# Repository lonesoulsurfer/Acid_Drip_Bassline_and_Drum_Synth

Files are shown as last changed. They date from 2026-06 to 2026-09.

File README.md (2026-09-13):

# Acid Drip - Bassline Synth, Drift Synth & Drum Machine

Youtube Video (click the image) - Acid Drip Demo (https://youtu.be/anotb2mvv04) 

An RP2040-based acid bassline synthesizer and drum machine built on the Mozzi audio library. Three instruments in one device: a 16-step acid sequencer, a second synth voice called DRIFT, and a 16-pattern drum groove box, all running simultaneously on dual cores with a 320x240 ILI9341 TFT display and 16 Cherry MX pads.

NOTE: the images of the synth are V1. V2 is what I have provided in this repo and looks a little different (extra pot for mix added).

NOTE: V5 firmware adds a second synth voice called DRIFT, pattern chaining for the acid save slots, a MIX EDIT mode for balancing all three engines against each other, and a user editable custom drum pattern, on top of everything V4 had. See DRIFT Synth, Pattern Chaining, MIX EDIT and Custom Pattern below for each.

<p align="center">
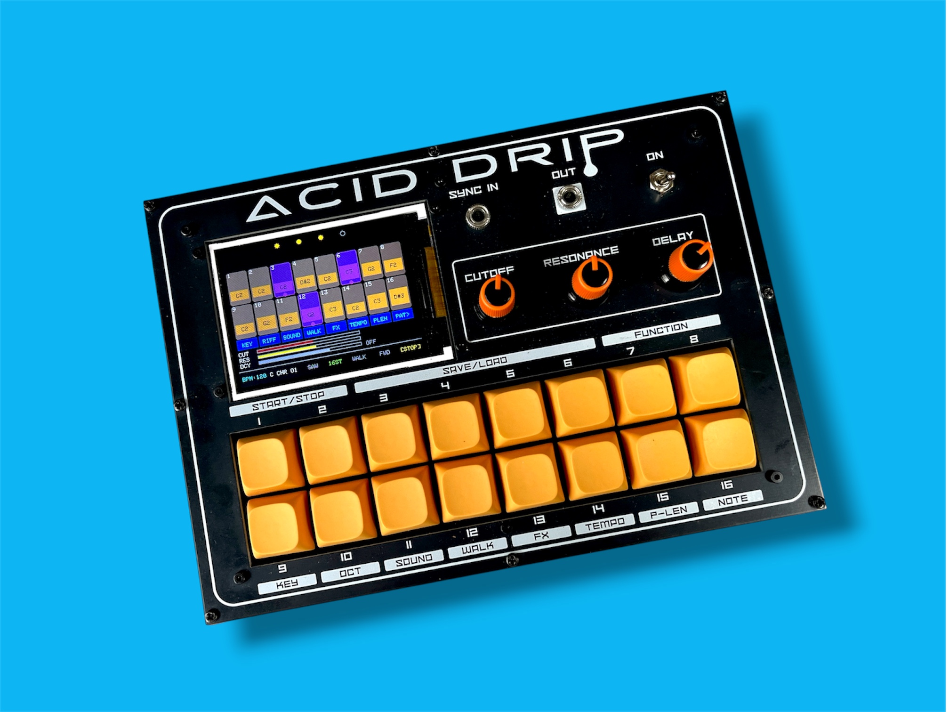
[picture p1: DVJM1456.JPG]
Acid Drip - angle view on cyan
  
  &nbsp;
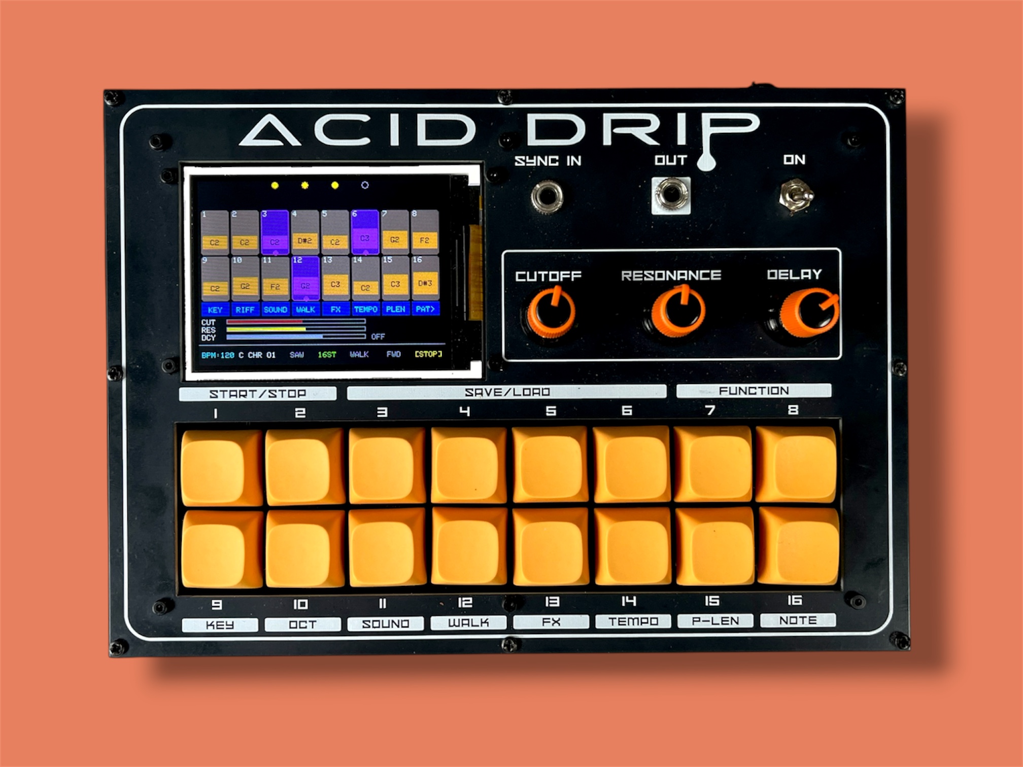
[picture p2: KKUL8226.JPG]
Acid Drip - front view on orange
  
  &nbsp;
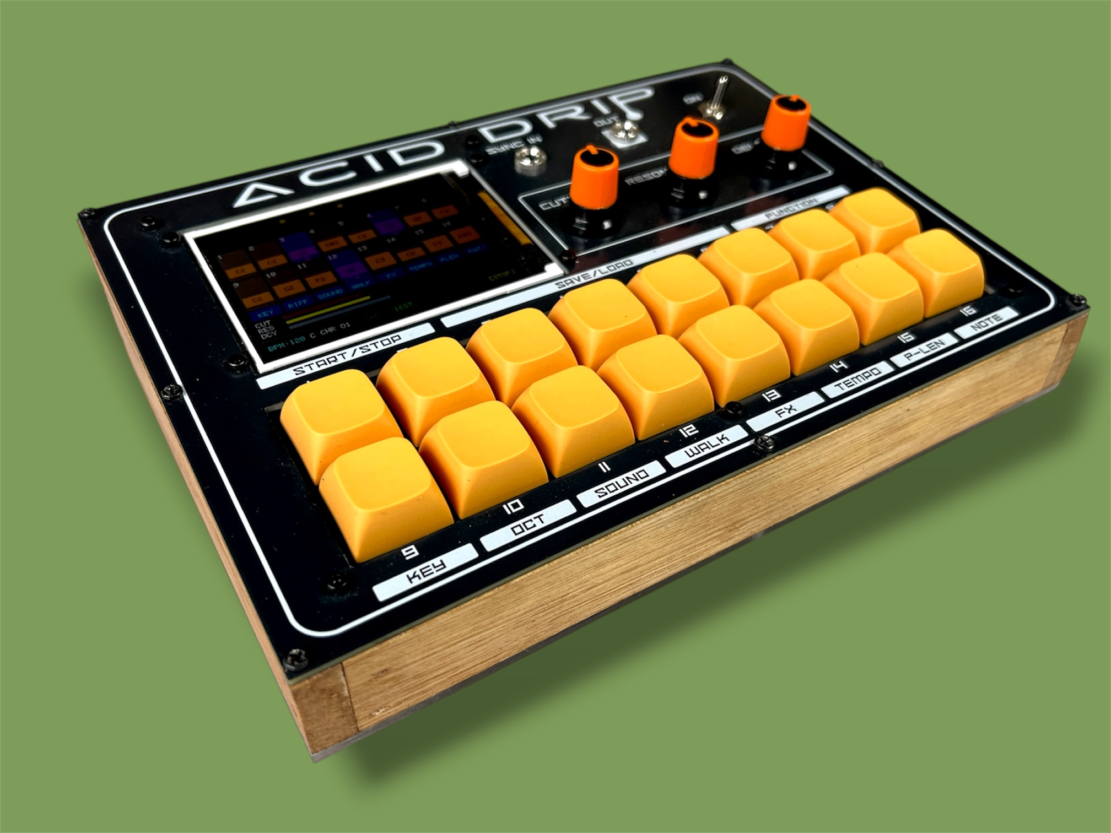
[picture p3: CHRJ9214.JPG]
Acid Drip - perspective view on green
  
</p>

---

## Hardware

| Component | Detail |
|---|---|
| MCU | RP2040 (Raspberry Pi Pico or equivalent) |
| Display | ILI9341 320x240 TFT |
| Pads | 16x Cherry MX switches (2 rows of 8) |
| Pots | 3x analog (CUT, RES, DECAY) |
| Audio out (acid) | GP15 -> 100R + 10nF RC filter -> 3.5mm jack |
| Audio out (drums) | GP2 -> 470R resistor -> 3.5mm jack. In V5 this output also carries the DRIFT synth voice, summed with the drums |
| Sync in/out | GP2 (hardware SPDT switch selects drum/DRIFT audio OR sync). Direction (in or out) is chosen from an on-screen menu at boot, see Sync In/Out below |

### Wiring

```
TFT   : SCK=GP6  SDA=GP7  RST=GP8  DC=GP10  CS=GP13
Pots  : CUT=GP26  RES=GP28  DCY=GP27
Sync  : IN/OUT=GP2
Audio : Acid=GP15   Drums/DRIFT=GP2

Top row pads (steps 1-8):
  GP14=pad1  GP12=pad2  GP11=pad3  GP16=pad4
  GP17=pad5  GP19=pad6  GP20=pad7  GP21=pad8

Bottom row pads (steps 9-16 / FUNC select):
  GP0=pad9   GP1=pad10  GP3=pad11  GP4=pad12
  GP5=pad13  GP9=pad14  GP18=pad15 GP22=pad16
```

---

## Dependencies

Install via Arduino Library Manager:

- **Mozzi** (audio synthesis engine)
- **Adafruit GFX**
- **Adafruit ILI9341**

Board package: **Raspberry Pi Pico/RP2040** (Earle Philhower core)

---

## Files

This repo has two firmware versions, each in its own folder. They are separate sketches, not meant to be merged.

### V4 (`Acid_Drip_Drum_Acid_V4`)

| File | Description |
|---|---|
| `Acid_Drip_V4.ino` | Main sketch, acid synth engine, sequencer, UI |
| `BeatMachine_V4.ino` | Drum machine tab, DrumKid engine, 8 instruments |
| `beats.h` | 16 preset drum patterns (techno, house, hip-hop, etc.) |
| `sample0-7.h` | Drum samples stored as int8 arrays in flash (PROGMEM) |

### V5 (`Acid_Drip_Drum_Acid_Drift_V5`)

| File | Description |
|---|---|
| `Acid_Drip_V5_Drum_Acid_Drift.ino` | Main sketch, acid synth engine, sequencer, UI, MIX EDIT |
| `Drift.ino` | DRIFT tab, the second synth voice engine |
| `BeatMachine2.ino` | Drum machine tab, DrumKid engine, 8 instruments, custom pattern editor |
| `beats.h` | 16 drum patterns: 15 fixed presets plus one user editable CUSTOM slot |
| `sample0-7.h` | Drum samples stored as int8 arrays in flash (PROGMEM) |

V5 adds a second synth voice (DRIFT), pattern chaining, per engine level mixing (MIX EDIT), and a user editable custom drum pattern, all on top of everything V4 already had. Pick whichever folder matches the firmware you want to flash.

---

## Acid Synthesizer

### Pad Layout

```
+---------+---------+---------+---------+---------+---------+---------+---------+
|    1    |    2    |    3    |    4    |    5    |    6    |    7    |    8    |
|  step   |  step   |  step   |  step   |  step   |  step   |  step   |  step   |
|    1    |    2    |    3    |    4    |    5    |    6    |    7    |    8    |
+---------+---------+---------+---------+---------+---------+---------+---------+
|    9    |   10    |   11    |   12    |   13    |   14    |   15    |   16    |
|   KEY   |  RIFF   |  SOUND  |  WALK   |   FX    |  TEMPO  |  PLEN   |  PAT>   |
+---------+---------+---------+---------+---------+---------+---------+---------+
  (bottom row labels show only in FUNC mode)
```

### Step Editing

| Action | Result |
|---|---|
| Short press a pad | Toggle step on/off |
| Long press x1 | Toggle accent |
| Long press x2 | Toggle glide |
| Hold pad + turn CUT pot | Set step note (scale-quantised) |

### Chords

| Chord | Action |
|---|---|
| Pads 1+2 | Play / Stop |
| Pads 1+2 (hold 0.5s) | Factory reset. V5 scopes this to whichever engine is currently the edit focus: acid or DRIFT. Drums have their own separate reset, hold pads 1+2 for 1s while in drum mode |
| Pads 7+8 | Enter / exit FUNC mode |
| Pads 9+10 | Switch to drums (from acid or DRIFT), or back to whichever of acid/DRIFT was last active (from drums) |
| Pads 9+10+11 (hold 0.5s) | V5 only. From acid: go to DRIFT. From DRIFT: back to acid. From drums: no-op, see DRIFT Synth below |
| Pads 11+12+13+14 (hold 1s) | Toggle Acid Walks easter egg |
| Pads 12+13 | Enter / exit chain-build mode |
| Pads 15+16 (hold 1s) | V5 only. Toggle MIX EDIT mode (replaces V4's Accent Edit, see below) |

### Save / Load (hold pads 7+8)

- **Tap** pads 3/4/5/6 to load from slot 1/2/3/4
- **Hold** pads 3/4/5/6 for 1 second to save to slot 1/2/3/4
- Slot status shown top-right (yellow dot = saved, grey = empty)

In V5, each slot saves and loads the acid pattern, DRIFT, and the drum beat together, whichever of the three actually have data saved in that slot. The gesture is identical from the acid screen or the drum screen; either one saves and loads all three engines at once. Loading a slot also restores each engine's play/stop state exactly as it was at save time: an engine that was stopped when you saved goes silent on load even if it is currently playing, and an engine that was playing starts up again, in sync with the others. Any engine with no data in that slot is left exactly as it currently is. Tapping an empty slot shows an "empty" indicator instead of loading anything. In V4, a slot only covered whichever single engine you were on when you saved, and play state was not part of it.

Holding pads 3+4+5+6 together for 1 second, while on the acid or DRIFT screen, wipes the acid pattern out of all 4 slots at once (a "clear all" separate from the per-slot save/hold gesture above). Because V5 slots hold all three engines together, this only clears the acid portion of each slot; any DRIFT or drum data saved in those same slot numbers is left alone. This gesture is unchanged from V4, it was already in the firmware but missing from this document.

### Pattern Chaining (V5 only)

Link the 4 save slots into a longer playback sequence, up to 16 positions, in any order, with repeats.

**Building a chain:**

1. Tap pads 12+13 together to enter chain-build mode. The screen switches to a dedicated chain-builder view.
2. Tap pads 3/4/5/6 to append that slot to the chain. Tapping the same pad more than once repeats that slot, for example tapping 3, 3, 4, 5, 6, 6 builds a chain that plays slot 1 twice, then slot 2, slot 3, and slot 4 twice.
3. Tap pads 12+13 again to exit and start playback. The chain begins automatically, even if nothing was playing yet.

Each chain position plays through one full loop of that slot's own saved pattern length before advancing to the next position: a slot saved at 16 steps plays 16 steps, a slot saved at 8 steps plays 8, and so on. When the chain reaches the end it loops back to the first position.

Pads 7+8 (FUNC) cancel an in-progress build without starting playback. Tapping 12+13 again at any other time, including while a chain is already playing, drops the current chain and starts a fresh build.

A small "CH" indicator appears next to the slot status dots whenever a chain is actively playing.

Chains are session-only and are not saved to EEPROM, so rebuilding one takes a few seconds if needed again after a power cycle. Chaining currently works in the acid synth only, not drum mode.

### FUNC Mode (enter with pads 7+8)

| Pad | Function | Options |
|-----|---|---|
| 9 | KEY | Root note: C D Eb F G Ab Bb B |
| 10 | RIFF | Load preset riff pattern: DFLT / SQNCE / FUNK / MINI / JUMP / RAVE / SYNC / DARK |
| 11 | SOUND | Synth voice: SAW / SQR / SINE / PWM / CSAW / CSQR / CSIN / SUBSQ |
| 12 | WALK | Note walk: OFF / 4TH / OCTWAVE / 5TH / BOUNCE / MIN3RD / VAMP3 / RANDOM |
| 13 | FX | Enter FX assign sub-mode |
| 14 | TEMPO | Preset BPM: 100/110/120/128/133/138/145/160, or tap repeatedly for tap tempo |
| 15 | PLEN | Pattern length: 1 / 2 / 3 / 4 / 6 / 8 / 12 / 16 |
| 16 | PAT> | Playback order: FWD / CW / ALT / REV / SKIP2 / SKIP3 / PING / RND |

> Note: there is currently no live scale-type or octave selector. `seq.scale`/`seq.octave` are only set when loading a saved patch slot.

### FX Assign (FUNC -> pad 13)

1. Press a top-row pad to select an effect:
   `None / Oct Up / Retrigger / Stutter / Maj Step / Min Step / Dom7 Step / Dim Step`
2. Press any pad 1-16 to assign that effect to that step.
3. Tap the selected FX pad again to deselect.
4. Long-hold pad 1 to clear all step effects.
5. Pads 7+8 to exit back to main screen.

### MIX EDIT (V5 only)

Hold **pads 15+16** for 1 second to enter MIX EDIT. The three pots trim the output level of each of the three engines independently:

| Pot | Engine |
|-----|---|
| CUT | Acid |
| RES | DRIFT |
| DCY | Drums |

This is a digital trim sitting on top of the physical mix pot, which only ever blends acid (GP15) against DRIFT plus drums (GP2) as one combined pair. MIX EDIT is what actually lets DRIFT be balanced against drums on its own, which the physical pot alone cannot do. Pot pickup applies here too: each pot stays inert until it has been moved past its position at the moment MIX EDIT was entered, so opening the page never snaps a level to wherever a pot happens to be sitting. Hold pads 15+16 again to exit; the three levels save to EEPROM automatically and persist across power cycles until changed again.

Accent Edit mode from V4 has been removed in V5 and replaced by MIX EDIT on the same pads 15+16 gesture. Accent tone is now a fixed setting rather than something you tune live.

### Acid Walks (Easter Egg)

Hold **pads 11+12+13+14** for 1 second to toggle a hidden mode with 8 preset patterns inspired by classic acid/house tracks, each pre-loaded with its own key, tempo, length and sound. Select a pattern with pads 1-8. FUNC mode, FX assignment and drum mode all continue to work normally while active. Hold the same 4-pad chord again to exit.

---

## DRIFT Synth (V5 only)

DRIFT is a second, independent synth voice that sits alongside the acid engine, with its own 16 step pattern, its own bank of 16 selectable synth engines, and its own FUNC page. It renders digitally and sums with the drum machine on the GP2 output, so DRIFT is only heard through the drums/DRIFT output, not the acid output.

### Switching to DRIFT

Which screen pads 9+10 and 9+10+11 land you on depends on where you currently are, not a fixed rule, so here is the full table:

| Currently on | Pads 9+10 | Pads 9+10+11 (hold 0.5s) |
|---|---|---|
| Acid | Go to drums | Go to DRIFT |
| DRIFT | Go to drums | Back to acid |
| Drums | Back to whichever of acid/DRIFT was active before | No-op, stays in drums |

DRIFT is only reachable from the acid screen, not directly from drums. Pressing 9+10+11 while already in drums is a deliberate no-op rather than a shortcut into DRIFT, since a three-pad press is easy to land imprecisely and jumping straight into DRIFT from drums made it too easy to end up somewhere unintended. To get from drums to DRIFT, go back to acid first (9+10), then 9+10+11.

Switching edit focus only changes which engine the pads and pots are currently controlling, not what is audible. Acid, DRIFT and drums can all be playing at once; each is started independently and the overall balance is set by the physical mix pot and MIX EDIT (see above).

### Step Editing

Once DRIFT is the edit focus, the same 16 pad grid used for acid steps toggles DRIFT's own step pattern instead. Holding a key on the KBRD page (see FOLW below) transposes the running line live while held.

### FUNC Mode (DRIFT)

With DRIFT as the edit focus, pads 7+8 open DRIFT's own FUNC page, separate from the acid FUNC page:

| Pad | Function | Options |
|-----|---|---|
| 9 | SND1 | Synth engine, page 1 of 2: SUBSIN / DTSQR / FMBEL / RINGM / CLICK / FOLDR / PWM / UNISN |
| 10 | SND2 | Synth engine, page 2 of 2: SAW / SUBDIV / NOIZ / VOWEL / ARPG / GONG / CRUSH / GATE |
| 11 | FOLW | Pitch mode: F+8 / F-8 / F+5 / F+3 (follow the acid voice's last note, plus an interval) / FOLW (plain follow) / ARP+ / AR+- / WALK |
| 12 | ECHO | Delay: OFF / 8D / 1/4 / 4D / 1/2 / 8FB / 4FB / 2FB |
| 13 | VERB | Reverb size: OFF / SML / MED / BIG / HALL / MEDW / BIGW / WASH |
| 14 | PATT | 8 user savable pattern slots, S1 to S8. See PATT below |
| 15 | EVOL | EVOLVE generative mutation: OFF / OCTL / ADD1 / DEEP / STUT / HVY / WILD / MAX |
| 16 | REC | Pot motion recorder. See REC below |

Each of the 16 synth engines maps the CUT/RES/DCY pots slightly differently (roughly octave, a character/detune/amount control, and decay time), so the same three pots do different things depending which engine is selected.

### PATT (pattern slots)

8 slots (S1 to S8) hold DRIFT's own saved step patterns, separate from the acid save slots. A tap loads a slot (blank if nothing has been saved there yet); a hold saves whatever is currently on the grid as that slot. All 8 slots start blank. These are on/off step patterns only; what note actually plays at each step is decided separately by the FOLW/pitch mode.

### EVOLVE (EVOL)

A generative mutation system with 7 named intensity modes (OCTL / ADD1 / DEEP / STUT / HVY / WILD / MAX) on top of OFF. When active, EVOLVE periodically nudges the DRIFT line away from its recorded pattern and back again; the mode selected sets how far it wanders and how often.

### Pot Motion Recorder (REC)

Short-tap the REC pad (16) to start recording, tap again to stop. While recording, moving any of the three pots arms that pot's lane and captures its position on every step for one loop of the pattern. Release REC and the recorded lanes play back automatically each step, in time, while any pot you did not record stays live and playable as normal. Long-press REC to clear all recorded lanes. This lets a single loop carry pot automation, for example a filter sweep or a pitch rise that repeats every bar, without needing to hold the pot yourself.

---

## Beat Machine

Switch between acid and drum mode by pressing **pads 9+10 simultaneously**. In V5, holding pads 9+10+11 instead switches to DRIFT (see DRIFT Synth above). The sequencer state is preserved when switching between any of the three.

### Drum Instruments (8 tracks)

| Pad | Instrument |
|-----|---|
| 1 | Kick |
| 2 | Hi-hat (closed) |
| 3 | Snare |
| 4 | Rim |
| 5 | Tom |
| 6 | Bass 2 |
| 7 | Clap |
| 8 | Open hat |

### Pattern Selection

Short-tap any pad (1-16) to load that beat pattern. The current pattern name and number are shown on the display. Pads 1-5 double as drum edit pads (see below): a short tap selects the pattern, a long hold enters drum editing. In V5, pad 16 has an additional role: it also opens the CUSTOM pattern editor (see Custom Pattern below).

### Per-Drum Editing

Hold any of pads 1-5 (kick/hat/snare/rim/tom) and turn the pots:

- **CUT** -> pitch (exponential, pot centre = natural speed, each 64 units = one octave)
- **RES** -> decay length (exponential envelope from a 4ms blip to full sample tail)
- **DCY** -> volume

Pot pickup prevents value jumps when grabbing a control: each pot only responds once it has been physically moved past its position at the moment the pad was grabbed. Per-drum settings reset on pattern change and are saved with slots.

> Bass 2, Clap, and Open Hat (pads 6-8) cannot be edited via hold+pot. Pattern selection is their only pad function.

### Beat Machine FUNC Mode (pads 7+8)

| Label | Function | Detail |
|---|---|---|
| PTCH | Global pitch | Transposes all drums together; stacks on top of per-drum pitch |
| DRIV | Drive / saturation | Exponential pre-gain into a hard-knee saturator; top of the knob also adds bit crush |
| FILT | Bipolar DJ filter | Centre = bypass; below centre = lowpass sweep; above centre = highpass sweep |
| CHNC | Chance | Centre = as-is; below = thins existing hits (anchors held solid); above = adds ghost hits on empty steps |
| HMNZ | Humanize | Adds random velocity spread and per-hit micro-timing jitter; centre = robotic |
| SWNG | Swing | Delays odd 16th steps up to 60% of the step interval for a swung feel |
| ACNT | Accent depth | Centre = flat; above centre = on-beat emphasis; below centre = off-beat (pushed) emphasis |
| FILL | Procedural fill engine | See Fill Engine below |

All FUNC parameters except FILT and CHNC are saved with slots.

### Fill Engine (FUNC -> FILL)

The fill engine takes over the last few steps before a pattern boundary with a procedurally generated build, then lands on beat 1 with a kick and open hat.

**Pads 1-4** set the fill frequency:

| Pad | Label | Behaviour |
|-----|---|---|
| 1 | OFF | No fills |
| 2 | 1 BAR | Fill every 16 steps (4 steps long) |
| 3 | 2 BAR | Fill every 32 steps (6 steps long) |
| 4 | 4 BAR | Fill every 64 steps (8 steps long, half a bar) |

**Pads 5-8** set the fill type:

| Pad | Label | Behaviour |
|-----|---|---|
| 5 | HATS | Closed-hat build opening to an open hat on the tail; kick holds the floor |
| 6 | CLAP | Clap build over a steady half-time kick |
| 7 | SNARE | Flat snare rush with no kick; the landing slams |
| 8 | KIT | Descending tom for the first 70% of the window, then snare into the landing; KIT also adds a clap on the "1" |

> Pads 7 and 8 are also the FUNC-exit chord. SNARE and KIT selections register on release so the exit gesture takes priority.

**Editing the fill sound:** while in the FILL slot, the three pots control the lead voice's own pitch, decay length, and volume independently of the pattern's drum settings. These are saved with slots.

Density accelerates into the landing: the final quarter of the fill window schedules additional 32nd-note in-between hits so the build feels like it rushes into the "1".

### Preset Patterns

16 patterns selectable from the pad grid:

| # | Short name | Full name |
|---|---|---|
| 1 | BASC | BASIC |
| 2 | HOUS | HOUSE |
| 3 | TECH | TECHNO |
| 4 | ACID | ACID TRACK |
| 5 | HSOC | HI STATE |
| 6 | FUNK | FUNKY |
| 7 | SWNG | SWING |
| 8 | BKBT | BREAKBEAT |
| 9 | MINM | MINIMAL |
| 10 | LATN | LATIN |
| 11 | PCFC | PACIFIC ST |
| 12 | BLMN | BLUE MONDAY |
| 13 | DNBT | DRUM N BASS |
| 14 | VOOD | VOODOO RAY |
| 15 | GBLD | BUILD DOWN |
| 16 | CUST | CUSTOM (V5 only, user editable, see Custom Pattern below) |

> V4's pattern 16 was a fixed preset called JACK BEAT. V5 replaces it with the user editable CUSTOM slot described below.

### Custom Pattern (Pad 16, V5 only)

Pattern slot 16 is CUSTOM: a blank, user editable pattern rather than a fixed preset.

- **Quick tap pad 16** while not already editing to enter custom edit mode straight away. No hold required.
- **Tap pad 16** again once you are editing to toggle step 16 for whichever drum voice is currently selected, the same as tapping any other step pad.
- **Turn any pot** at any time while editing to set pitch/length/volume for the current voice, live, the same as normal per-drum editing.
- **Hold pad 16 for 0.4 seconds** to cycle to the next drum voice.
- **Hold pad 16 for 0.8 seconds** to exit and save.
- **Hold pad 16 for 2 seconds**, from either state, to wipe the whole custom pattern and start again.

A live legend appears along the bottom of the screen the moment pad 16 is pressed, listing each of the tiers above. They start out white and light up in their own colour as your hold time reaches that tier, so you can see what letting go will do before you commit to it.

### Save / Load (drum mode)

Same gesture as the acid synth: hold pads 7+8, then tap pads 3-6 to load from slot 1-4 or hold pads 3-6 for one second to save. This is the same unified save/load described above, it saves and loads acid, DRIFT and the drum beat together (including each engine's play/stop state) no matter which screen you trigger it from. Per-drum pitch/length/volume, global FUNC parameters, tempo, swing, fill settings, and the selected pattern are all stored as part of it.

Holding pads 3+4+5+6 together for 1 second while in drum mode (and not holding pads 7+8) wipes the drum beat out of all 4 slots at once, the drum-side equivalent of the acid clear-all gesture above. It only clears the drum portion of each slot; acid and DRIFT data saved in those same slot numbers is untouched.

---

## Sync In / Sync Out / Drum Mode (GP2)

GP2 is shared between drum audio output (in V5, also the DRIFT synth voice, which sums with the drums on the same output) and the sync clock jack, in either direction. A physical **SPDT switch on the PCB** routes the pin to either function.

**Boot detection selects the mode and, for sync, the direction:**

- **Drum mode (default):** GP2 is claimed by PWMAudio DMA and outputs drum (and, in V5, DRIFT) audio. Switch in the DRUMS position. Hold nothing at power-on.
- **Sync In mode:** Hold **pad 14** at power-on. A "SYNC MODE" menu appears; press **pad 1** for Sync In. GP2 is configured as a digital input and listens for an external clock pulse, driving this device's tempo from it. Switch in the SYNC position.
- **Sync Out mode:** Hold **pad 14** at power-on. On the same "SYNC MODE" menu, press **pad 2** for Sync Out. GP2 becomes a clock output instead, generating a DIN-sync-style pulse train (24 pulses per quarter note, matching the TB-303/808/909 standard) from this device's own tempo, so it can drive other gear as the master. Switch in the SYNC position.

A cyan "SYNC MODE" menu appears when pad 14 is held at boot, prompting for pad 1 (Sync In) or pad 2 (Sync Out); a "SYNC IN ACTIVE" or "SYNC OUT ACTIVE" confirmation follows briefly once chosen.

Sync Out only emits pulses while the acid transport is running (pads 1+2). It goes idle (line held low) when stopped rather than free-running through a stopped pattern. The pulse width is fixed at 2ms regardless of tempo. The info bar's "S" indicator (top right) is cyan for Sync In and magenta for Sync Out, so you can tell direction at a glance while playing.

> The switch position and the held pad must match. If the switch is in SYNC position but the device boots into drum mode, GP2 will try to drive audio into the sync signal line. In V5, sync mode (either direction) silences drums and DRIFT together, since both share GP2 with the sync jack; the acid voice on GP15 is unaffected either way. Sync In and Sync Out cannot run at the same time, since they both need sole use of GP2, one as an input, one as an output; the boot menu is where you pick one for that session.

---

## Architecture Notes

The firmware runs on both RP2040 cores:

- **Core 0**: Mozzi audio engine (acid synthesis, DRIFT synthesis in V5, and drum mixing), pad scanning, sequencer logic
- **Core 1**: TFT display rendering, drum sample buffer filling (via `bmFillDrumBuffer`)

The two cores communicate via the RP2040 inter-core FIFO. All SPI/TFT calls happen exclusively on core 1.

The drum clock is driven directly by the acid sequencer's `advanceStep()` call rather than an independent timer. In V5, DRIFT's own step advance is driven from the same call. This guarantees zero drift between all engines at all tempos and pattern lengths.

The drum audio path on GP2 uses a separate `PWMAudio` DMA instance at 488kHz carrier (versus Mozzi's 48kHz on GP15). This prevents carrier-frequency beating between the two audio outputs that would otherwise cause the acid synth to sound quieter when drums (and, in V5, DRIFT) are playing. DRIFT is rendered digitally and summed into this same GP2 path alongside the drums, rather than having a separate output of its own.

MIX EDIT's per-engine levels (V5) are a digital trim applied on top of this, independent of the physical mix pot, and are stored in EEPROM alongside the other saved settings.

---

## Credits

- Acid synthesis engine adapted from *Badass Bass*  https://www.youtube.com/watch?v=MvDILHYImc4
- Drum engine adapted from **DrumKid** by Matt Bradshaw  https://www.youtube.com/watch?v=509iZGjnVhM
- Built with the [Mozzi](https://sensorium.github.io/Mozzi/) audio library
- Hardware design and firmware by Marcus ([lonesoulsurfer](https://github.com/lonesoulsurfer))

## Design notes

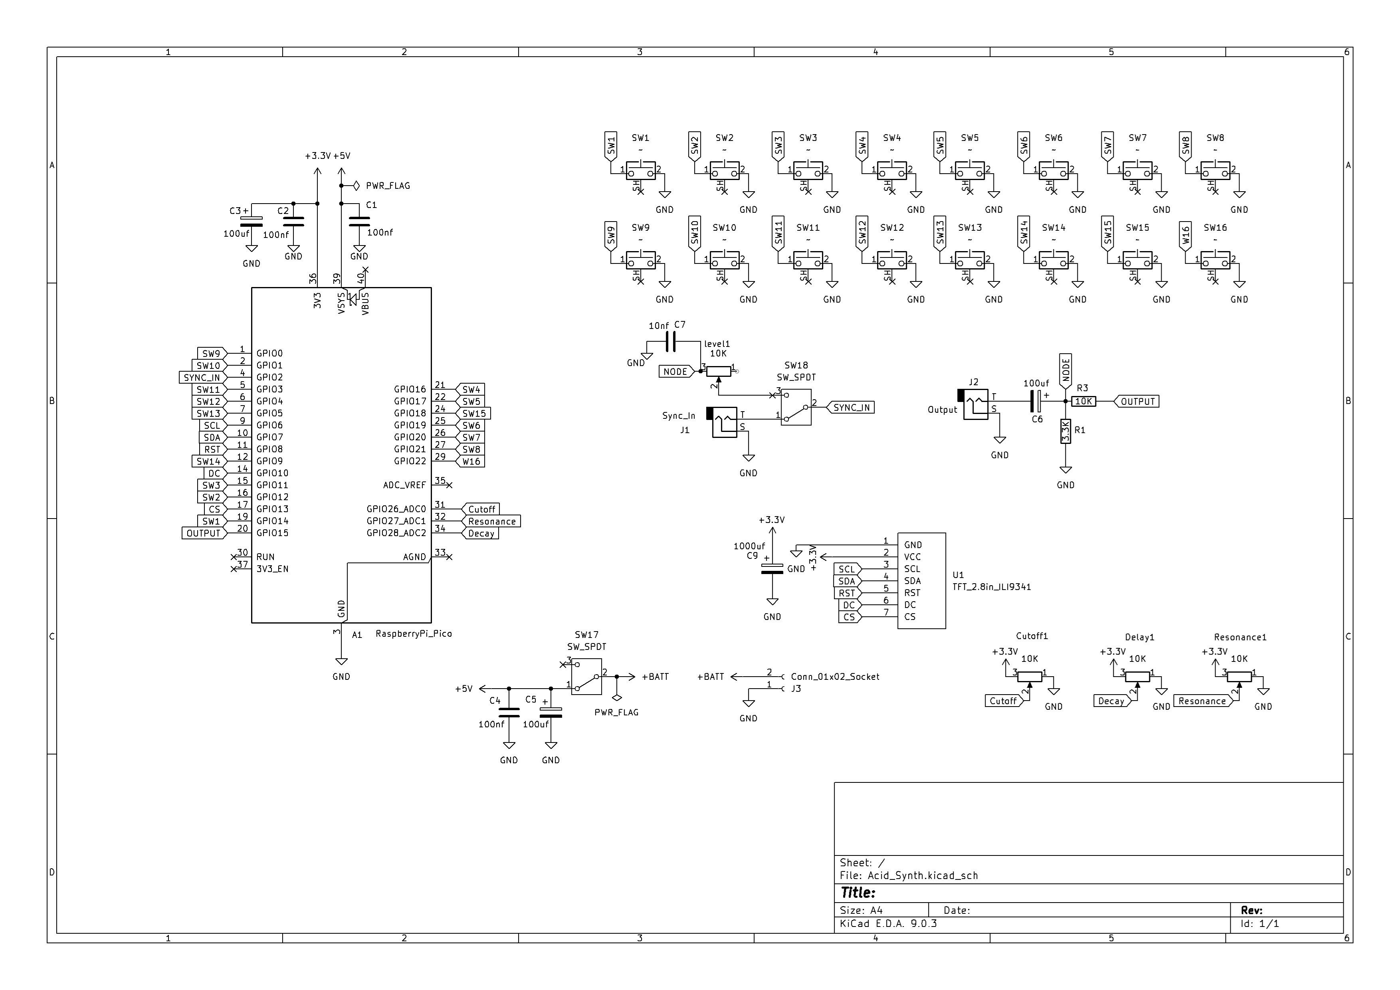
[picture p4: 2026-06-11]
Schematic.png

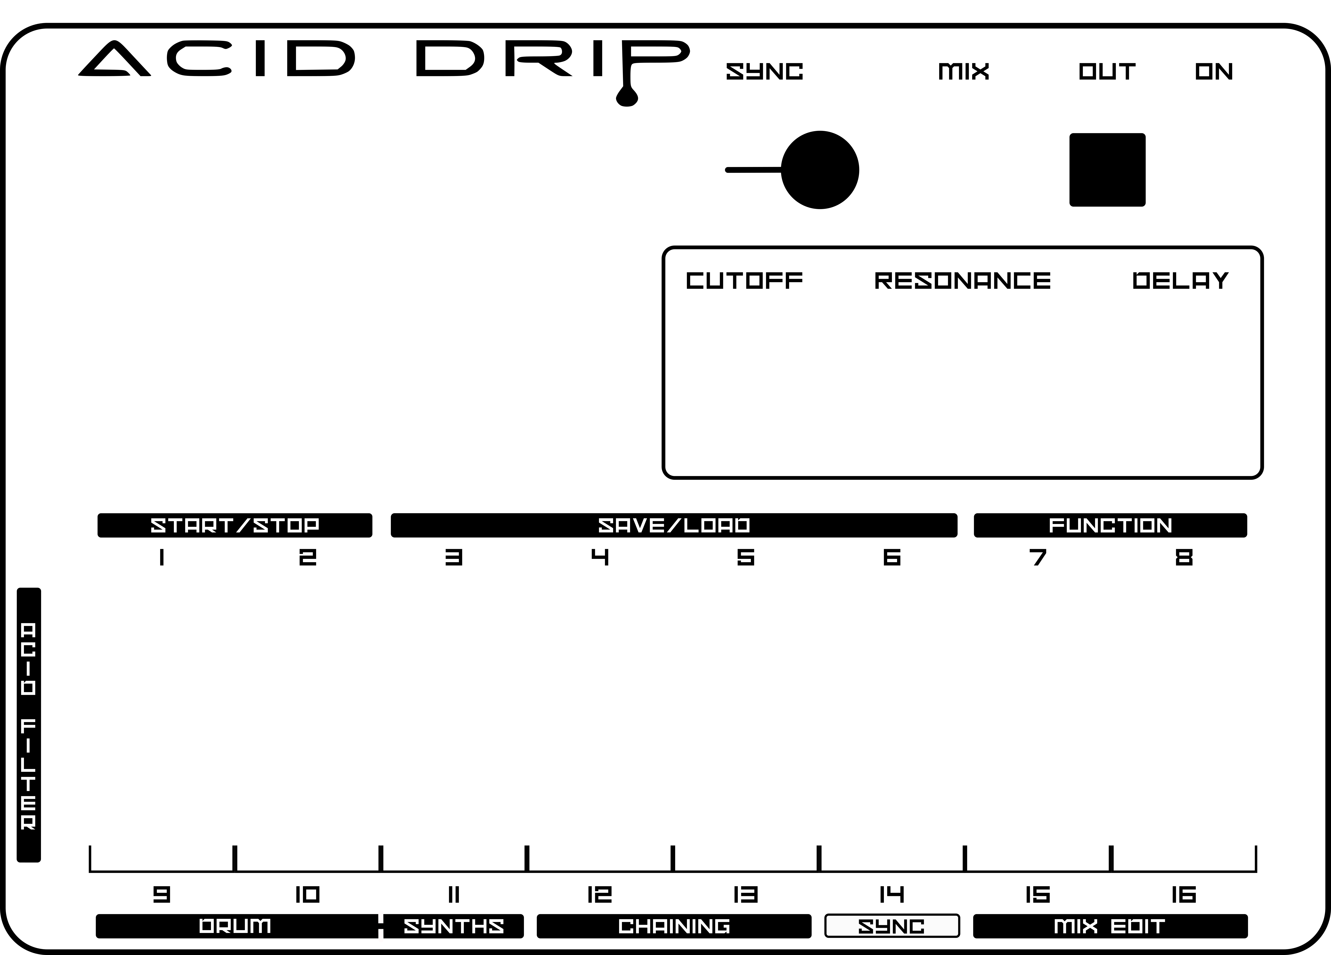
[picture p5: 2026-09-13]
Front Panel Design/Acid - Front Panel - Inkscape.png

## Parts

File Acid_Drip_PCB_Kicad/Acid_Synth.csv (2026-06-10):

Reference | Qty | Value | DNP | Exclude from BOM | Exclude from Board | Footprint | Datasheet
A1 | 1 | RaspberryPi_Pico |  |  |  | Module_RaspberryPi_Pico:RaspberryPi_Pico_Common | https://datasheets.raspberrypi.com/pico/pico-datasheet.pdf
C1,C2,C4 | 3 | 100nf |  |  |  | Capacitor_THT:C_Disc_D4.3mm_W1.9mm_P5.00mm | ~
C3,C5,C6 | 3 | 100uf |  |  |  | Capacitor_THT:CP_Radial_D5.0mm_P2.00mm | ~
C7 | 1 | 10nf |  |  |  | Capacitor_THT:C_Disc_D4.3mm_W1.9mm_P5.00mm | ~
C9 | 1 | 1000uf |  |  |  | Capacitor_THT:CP_Radial_D6.3mm_P2.50mm | ~
Cutoff1,Delay1,Resonance1 | 3 | 10K |  |  |  | Potentiometer_THT:Potentiometer_Alps_RK09K_Single_Vertical | ~
J1 | 1 | Sync_In |  |  |  | Connector_Audio:Jack_3.5mm_QingPu_WQP-PJ398SM_Vertical_CircularHoles | ~
J2 | 1 | Output |  |  |  | Connector_Audio:Jack_3.5mm_QingPu_WQP-PJ398SM_Vertical_CircularHoles | ~
J3 | 1 | Conn_01x02_Socket |  |  |  | Connector_JST:JST_PH_B2B-PH-K_1x02_P2.00mm_Vertical | ~
level1 | 1 | 50K |  |  |  | Potentiometer_THT:Potentiometer_Alps_RK09K_Single_Vertical | ~
R1 | 1 | 3.3K |  |  |  | Resistor_THT:R_Axial_DIN0207_L6.3mm_D2.5mm_P10.16mm_Horizontal | ~
R3 | 1 | 10K |  |  |  | Resistor_THT:R_Axial_DIN0207_L6.3mm_D2.5mm_P10.16mm_Horizontal | ~
SW1,SW2,SW3,SW4,SW5,SW6,SW7,SW8,SW9,SW10,SW11,SW12,SW13,SW14,SW15,SW16 | 16 | ~ |  |  |  | Button_Switch_Keyboard:SW_Cherry_MX_1.00u_PCB | ~
SW17,SW18 | 2 | SW_SPDT |  |  |  | MyProject:SW_SPDT_Toggle_QuarterInch_Bushing | ~
U1 | 1 | TFT_2.8in_ILI9341 |  |  |  | MyProject:TFT_2.8in_ILI9341

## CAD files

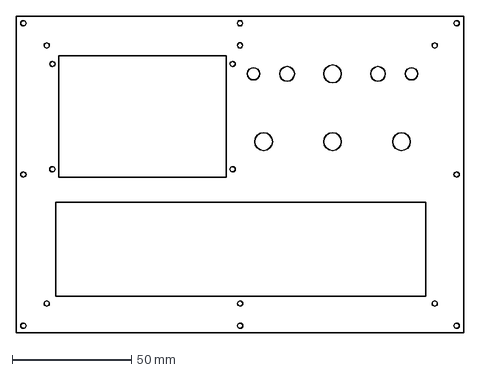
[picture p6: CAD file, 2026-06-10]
Front Panel Design/front panel - Fusion.dxf
188.0 x 133.0 mm

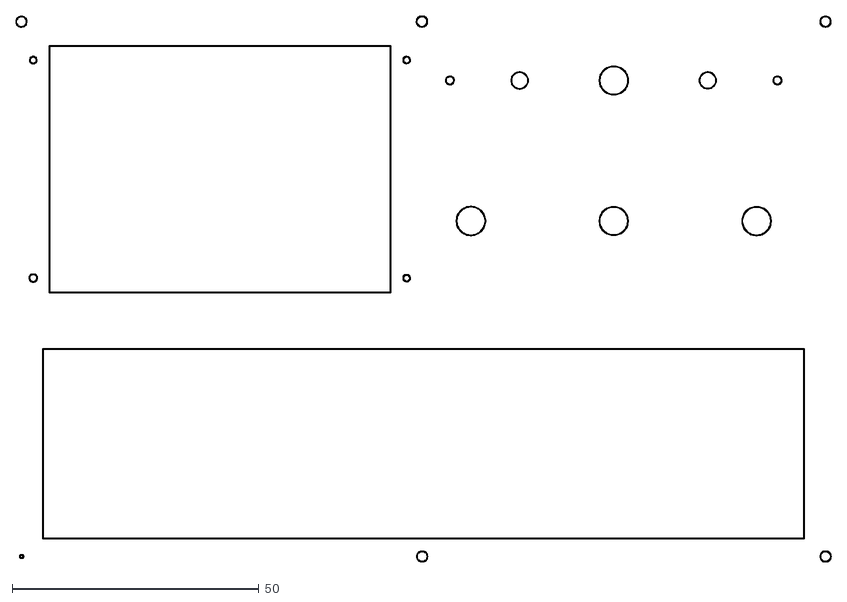
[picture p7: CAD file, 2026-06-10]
Front Panel Design/PCB/Acid_Synth-User_1.dxf
165.2 x 110.7

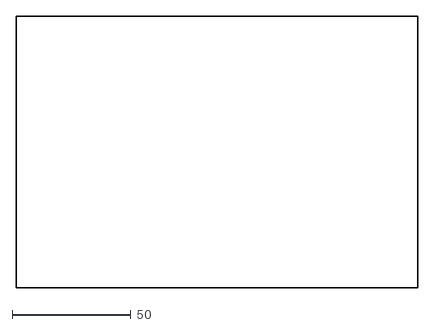
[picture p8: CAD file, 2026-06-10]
Front Panel Design/PCB/Acid_Synth-Edge_Cuts.dxf
169.0 x 114.5

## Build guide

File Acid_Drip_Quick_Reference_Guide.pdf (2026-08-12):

# Acid Drip

Bassline synth, DRIFT synth and drum machine. Quick reference guide (V5)

## Acid Pad Layout

1
Step 1

2
Step 2

3
Step 3

4
Step 4

5
Step 5

6
Step 6

7
Step 7

8
Step 8

9
KEY

10
RIFF

11
SOUND

### 12 WALK

13
FX

14
TEMPO

15
PLEN

16
PAT>

Bottom row labels only show in FUNC mode. Steps 9-16 are the same 8 pads.
Step Editing
ACTION | RESULT
Short press pad | Toggle step on/off
Long press x1 | Toggle accent
Long press x2 | Toggle glide
Hold pad + turn CUT | Set step note

## Core Chords

CHORD | ACTION
1+2 | Play / Stop
1+2 hold 0.5s | Reset current engine (acid/DRIFT). Drums: hold 1s in drum
mode
7+8 | Enter / exit FUNC mode
9+10 | Switch to drums, or back to acid/DRIFT
9+10+11 hold 0.5s | Acid to DRIFT and back. No-op from drums
11+12+13+14 hold
1s

Acid Walks easter egg

12+13 | Enter / exit chain-build mode
15+16 hold 1s | Toggle MIX EDIT mode

Save / Load (hold 7+8)

Tap 3/4/5/6 | Load slot 1/2/3/4
Hold 3/4/5/6 for 1s | Save to slot 1/2/3/4
Hold 3+4+5+6 for 1s Clear acid from all 4 slots (drum mode: clears drums instead)

Each slot saves acid, DRIFT and the drum beat together, plus play/stop state. Works from any screen.

## FUNC Mode (hold 7+8 to enter)

PAD | FUNCTION | OPTIONS
9 | KEY | Root note: C D Eb F G Ab Bb B
10 | RIFF | DFLT / SQNCE / FUNK / MINI / JUMP / RAVE / SYNC / DARK
11 | SOUND | SAW / SQR / SINE / PWM / CSAW / CSQR / CSIN / SUBSQ
12 | WALK | OFF / 4TH / OCTWAVE / 5TH / BOUNCE / MIN3RD / VAMP3 / RANDOM
13 | FX | Enter FX assign sub-mode
14 | TEMPO | Preset BPM or tap tempo
15 | PLEN | Pattern length: 1/2/3/4/6/8/12/16
16 | PAT> | FWD / CW / ALT / REV / SKIP2 / SKIP3 / PING / RND

FX Assign (FUNC, pad 13): press a top-row pad to pick an effect (None / Oct Up / Retrigger / Stutter / Maj Step / Min Step / Dom7 Step / Dim Step), then press any step pad to assign it. Tap the effect pad again to deselect. Long-hold pad 1 to clear all.

## Pattern Chaining

Link the 4 save slots into a sequence of up to 16 positions, with repeats.

1 | Tap 12+13 to enter chain-build mode
2 | Tap 3/4/5/6 to append that slot. Tap the same pad again to repeat it
3 | Tap 12+13 again to exit and start playback

Each position plays one full loop of that slot's own pattern length. Acid only, not drum mode. Chains are not saved to EEPROM.

## MIX EDIT

Hold 15+16 for 1s to trim the level of each engine independently.

POT | ENGINE
CUT | Acid
RES | DRIFT
DCY | Drums

Levels save to EEPROM automatically. Hold 15+16 again to exit.

## DRIFT Synth

A second, independent synth voice. Sums into the drums output (GP2).

## Switching Engines

CURRENTLY ON | 9+10 | 9+10+11 (HOLD 0.5S)
Acid | Go to drums | Go to DRIFT
DRIFT | Go to drums | Back to acid
Drums | Back to acid/DRIFT | No-op

DRIFT is only reachable from the acid screen. From drums, go back to acid first, then 9+10+11. Acid, DRIFT and drums can all play at once, switching only changes which one the pads/pots control.

## DRIFT FUNC Mode (7+8)

PAD | FUNCTION
9 | SND1, engine page 1 of 2
10 | SND2, engine page 2 of 2
11 | FOLW, pitch mode
12 | ECHO, delay
13 | VERB, reverb size
14 | PATT, 8 pattern slots
15 | EVOL, EVOLVE mutation
16 | REC, pot motion recorder

SND1

SUBSIN / DTSQR / FMBEL / RINGM / CLICK / FOLDR / PWM / UNISN SND2

SAW / SUBDIV / NOIZ / VOWEL / ARPG / GONG / CRUSH / GATE
FOLW (pitch mode)

F+8 / F-8 / F+5 / F+3 (follow acid's last note, plus an interval) / FOLW (plain follow) / ARP+ / AR+- / WALK EVOL (EVOLVE intensity)

OFF / OCTL / ADD1 / DEEP / STUT / HVY / WILD / MAX

## PATT, EVOLVE & REC

PATT 8 slots (S1-S8) for DRIFT's own step patterns. Tap loads, hold saves. Note/pitch is set separately by FOLW.
EVOLVE Periodically nudges the DRIFT line away from its recorded pattern and back. Intensity sets how far and how often.
REC Short-tap to start/stop recording pot movement over one loop. Recorded lanes play back automatically; unrecorded pots stay live. Long-press to clear.

## Beat Machine

Switch with pads 9+10. Sequencer state is preserved across all three engines.

## Drum Instruments

1 | Kick
2 | Hi-hat (closed)
3 | Snare
4 | Rim
5 | Tom
6 | Bass 2
7 | Clap
8 | Open hat

Short-tap any pad 1-16 to load that pattern. Pads 1-5 also double as drum edit pads (short tap = select, long hold = edit). Pads 6-8 are select-only.
Per-Drum Editing (hold pad 1-5)
CUT | Pitch
RES | Decay length
DCY | Volume

Custom Pattern (Pad 16)

Quick tap | Enter custom edit mode
Tap while editing | Toggle step 16 for current voice
Turn any pot | Set pitch/length/volume for current voice
Hold 0.5s | Cycle to next drum voice
Hold 1s | Exit and save
Hold 1.5s | Wipe pattern and restart

## Beat Machine FUNC (7+8)

LABEL | FUNCTION
PTCH | Global pitch, stacks on per-drum
DRIV | Drive / saturation, bit crush at top
FILT | Bipolar DJ filter (low/high sweep)
CHNC | Chance - thin or add ghost hits
HMNZ | Humanize - velocity & timing jitter
SWNG | Swing on odd 16th steps
ACNT | Accent depth, on/off-beat emphasis
FILL | Procedural fill engine, see below

Fill Engine

Pads 1-4 (frequency): OFF / 1 BAR / 2 BAR / 4 BAR
Pads 5-8 (type): HATS / CLAP / SNARE / KIT
Pots control the fill voice's pitch, decay and volume while FILL is selected. Density accelerates into the landing beat.

## 16 Preset Patterns

1 BASIC | 2 HOUSE | 3 TECHNO | 4 ACID TRACK
5 HI STATE | 6 FUNKY | 7 SWING | 8 BREAKBEAT
9 MINIMAL | 10 LATIN | 11 PACIFIC ST | 12 BLUE MONDAY
13 DRUM N BASS | 14 VOODOO RAY | 15 BUILD DOWN | 16 CUSTOM

Sync In / Out: hold pad 14 at power-on for a SYNC MODE menu. Press pad 1 for Sync In (external clock drives this device's tempo) or pad 2 for Sync Out (this device sends a 24 PPQN clock to other gear). Either way GP2 is taken from drum/DRIFT audio for that session, and requires the PCB switch in the SYNC position.

Acid Drip V5. Hardware and firmware by Marcus (lonesoulsurfer), github.com/lonesoulsurfer

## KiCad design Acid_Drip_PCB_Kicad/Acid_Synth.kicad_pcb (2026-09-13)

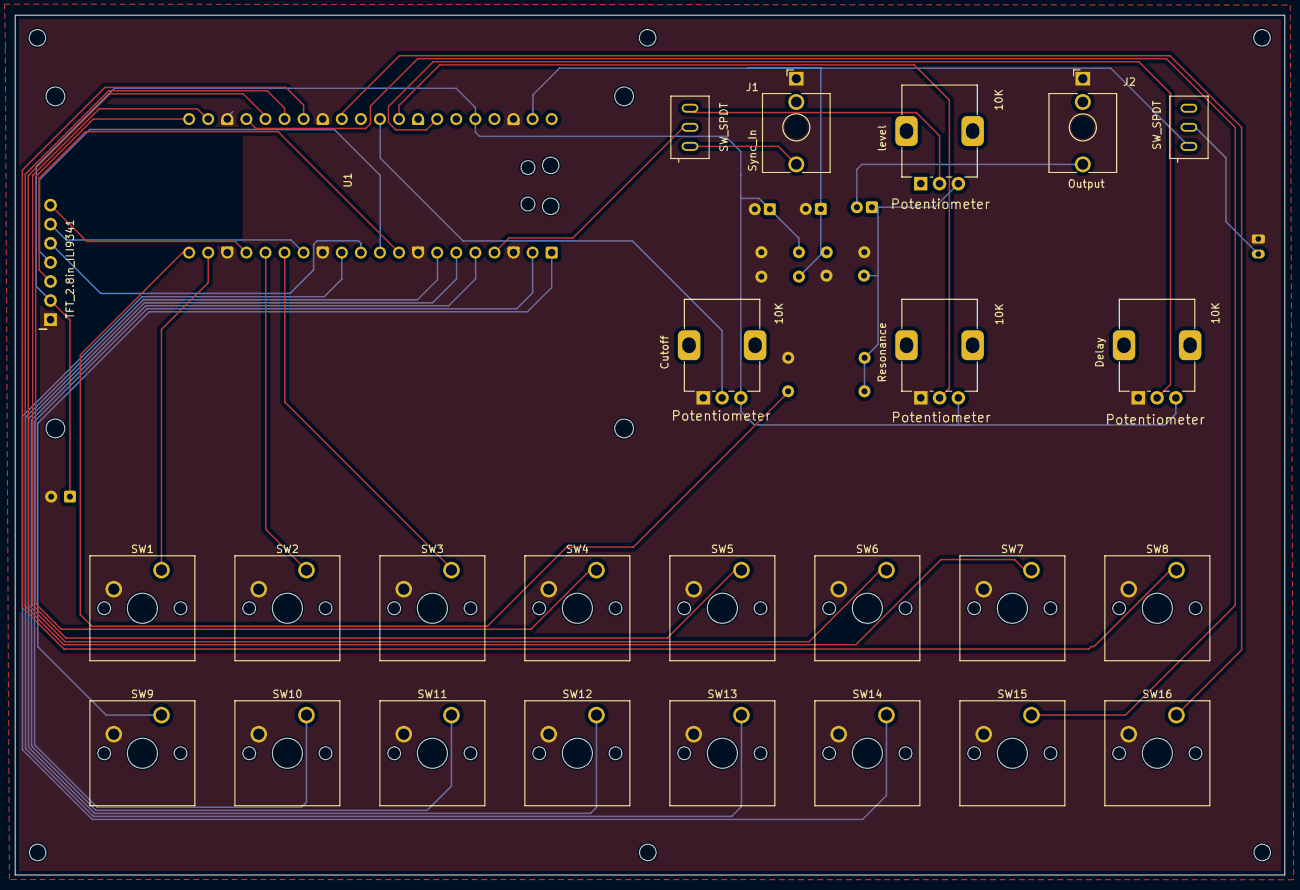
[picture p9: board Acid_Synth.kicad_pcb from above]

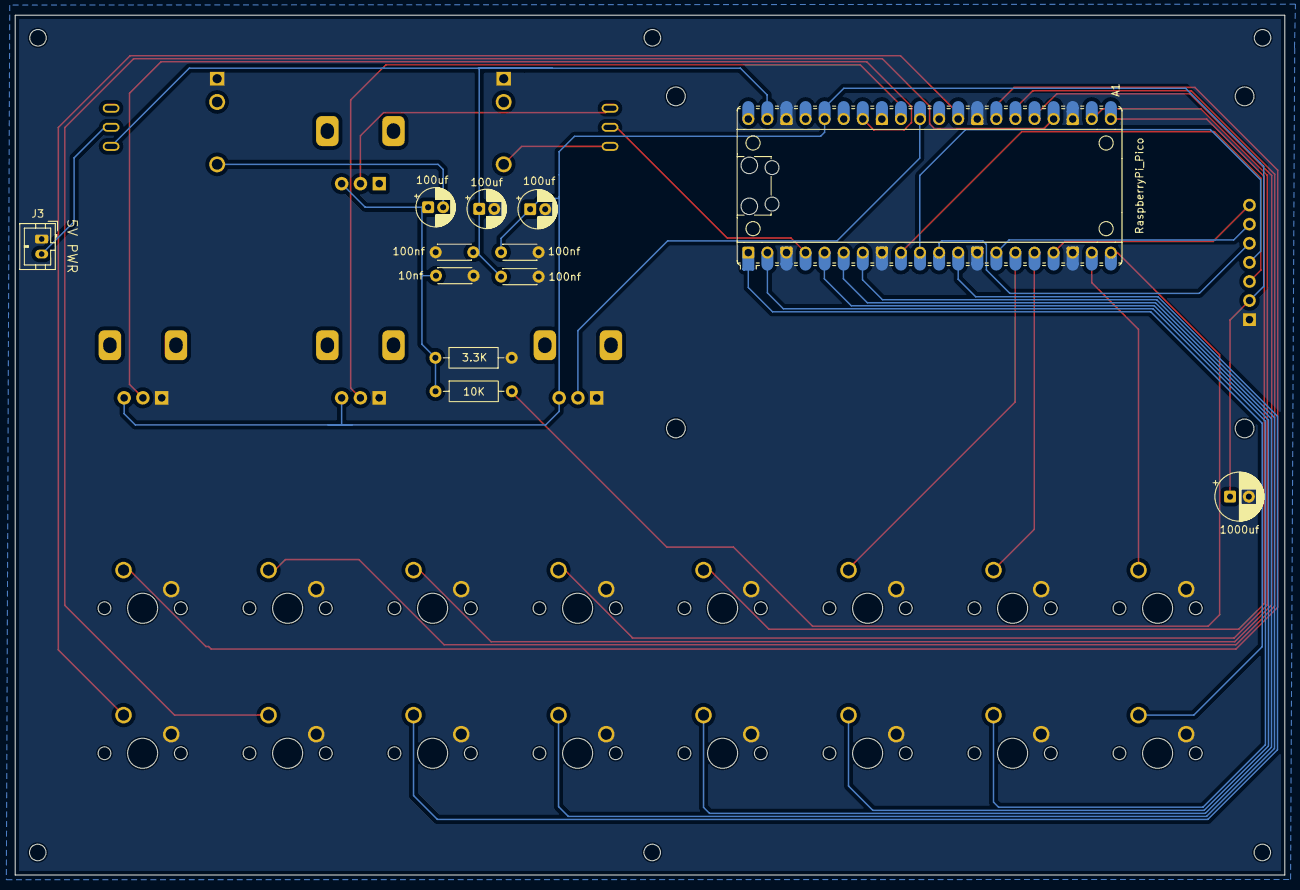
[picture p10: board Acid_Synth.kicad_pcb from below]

Board: 2 copper layers, 169.0 x 114.4 mm, 37 parts (12 on the bottom side), 33 nets.

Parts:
A1: RaspberryPi_Pico; RaspberryPi_Pico_Common
C1, C2, C4: 100nf; C_Disc_D4.3mm_W1.9mm_P5.00mm
C3, C5, C6: 100uf; CP_Radial_D5.0mm_P2.00mm
C7: 10nf; C_Disc_D4.3mm_W1.9mm_P5.00mm
C9: 1000uf; CP_Radial_D6.3mm_P2.50mm
Cutoff: 10K; Potentiometer_Alps_RK09K_Single_Vertical
Delay: 10K; Potentiometer_Alps_RK09K_Single_Vertical
J1: Sync_In; Jack_3.5mm_QingPu_WQP-PJ398SM_Vertical_CircularHoles
J2: Output; Jack_3.5mm_QingPu_WQP-PJ398SM_Vertical_CircularHoles
J3: Conn_01x02_Socket; JST_PH_B2B-PH-K_1x02_P2.00mm_Vertical
R1: 3.3K; R_Axial_DIN0207_L6.3mm_D2.5mm_P10.16mm_Horizontal
R3: 10K; R_Axial_DIN0207_L6.3mm_D2.5mm_P10.16mm_Horizontal
Resonance: 10K; Potentiometer_Alps_RK09K_Single_Vertical
SW1, SW2, SW3, SW4, SW5, SW6, SW7, SW8, SW9, SW10, SW11, SW12, SW13, SW14, SW15, SW16: SW_Cherry_MX_1.00u_PCB
SW17, SW18: SW_SPDT; SW_SPDT_Toggle_QuarterInch_Bushing
U1: TFT_2.8in_ILI9341
level: 10K; Potentiometer_Alps_RK09K_Single_Vertical

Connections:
+3.3V: A1.36 (3V3), C2.1, C3.1, C9.1, Cutoff.3, Delay.3, Resonance.3, U1.2 (VCC)
+5V: A1.39 (VSYS), C1.1, C4.1, C5.1, SW17.1 (A)
+BATT: J3.2, SW17.2 (B)
CS: A1.17 (GPIO13), U1.7 (CS)
Cutoff: A1.31 (GPIO26_ADC0), Cutoff.2
DC: A1.14 (GPIO10), U1.6 (DC)
Decay: A1.34 (GPIO28_ADC2), Delay.2
GND: A1.3 (GND), A1.8 (GND), A1.13 (GND), A1.18 (GND), A1.23 (GND), A1.28 (GND), A1.38 (GND), C1.2, C2.2, C3.2, C4.2, C5.2, C7.1, C9.2, Cutoff.1, Delay.1, J1.S, J2.S, J3.1, R1.1, Resonance.1, SW1.2, SW2.2, SW3.2, SW4.2, SW5.2, SW6.2, SW7.2, SW8.2, SW9.2, SW10.2, SW11.2, SW12.2, SW13.2, SW14.2, SW15.2, SW16.2, U1.1 (GND)
NODE: C6.1, C7.2, R1.2, R3.1, level.3
unnamed: C6.2, J2.T
unnamed: J1.T, SW18.1 (A)
OUTPUT: A1.20 (GPIO15), R3.2
RST: A1.11 (GPIO8), U1.5 (RST)
Resonance: A1.32 (GPIO27_ADC1), Resonance.2
SCL: A1.9 (GPIO6), U1.3 (SCL)
SDA: A1.10 (GPIO7), U1.4 (SDA)
SW1: A1.19 (GPIO14), SW1.1
SW2: A1.16 (GPIO12), SW2.1
SW3: A1.15 (GPIO11), SW3.1
SW4: A1.21 (GPIO16), SW4.1
SW5: A1.22 (GPIO17), SW5.1
SW6: A1.25 (GPIO19), SW6.1
SW7: A1.26 (GPIO20), SW7.1
SW8: A1.27 (GPIO21), SW8.1
SW9: A1.1 (GPIO0), SW9.1
SW10: A1.2 (GPIO1), SW10.1
SW11: A1.5 (GPIO3), SW11.1
SW12: A1.6 (GPIO4), SW12.1
SW13: A1.7 (GPIO5), SW13.1
SW14: A1.12 (GPIO9), SW14.1
SW15: A1.24 (GPIO18), SW15.1
SYNC_IN: A1.4 (GPIO2), SW18.2 (B)
W16: A1.29 (GPIO22), SW16.1

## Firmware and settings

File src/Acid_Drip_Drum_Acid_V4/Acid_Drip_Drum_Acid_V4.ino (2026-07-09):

/*
 * =====================================================================
 *              Acid Drip - RP2040 Acid Bassline Synthesizer
 *              Synthesis engine ported from reference "Badass Bass"
 * =====================================================================
 *
 * BUTTON LAYOUT (2 rows of 8 pads):
 *
 *   ┌─────┬─────┬─────┬─────┬─────┬─────┬──────┬──────┐
 *   │  1  │  2  │  3  │  4  │  5  │  6  │  7   │  8   │
 *   │step │step │step │step │step │step │step  │step  │
 *   │ 1   │ 2   │ 3   │ 4   │ 5   │ 6   │ 7    │ 8    │
 *   ├─────┼─────┼─────┼─────┼─────┼─────┼──────┼──────┤
 *   │  9  │ 10  │ 11  │ 12  │ 13  │ 14  │  15  │  16  │
 *   │KEY  │RIFF │SOUND│WALK │ FX  │TEMPO│PLEN  │PAT>  │
 *   └─────┴─────┴─────┴─────┴─────┴─────┴──────┴──────┘
 *   (bottom row labels only visible in FUNC mode)
 *
 * PAD FUNCTIONS (normal mode):
 *   Short press         : Toggle step on/off
 *   Long press ×1       : Toggle accent
 *   Long press ×2       : Toggle glide
 *   Hold + CUT pot      : Set step note (scale-quantised)
 *   All 16 pads are full steps — no dedicated buttons
 *
 * CHORD: PLAY (pads 1+2 simultaneously):
 *   Start / Stop sequencer
 *   Long hold (1s+)     : Factory reset
 *
 * CHORD: FUNC (pads 7+8 simultaneously):
 *   Toggle FUNC mode on/off
 *   Exits FX assign sub-mode if active
 *
 * SAVE / LOAD (while holding pads 7+8):
 *   Tap pad 3/4/5/6     : Load patch from slot 1/2/3/4
 *   Hold pad 3/4/5/6    : Save patch to slot 1/2/3/4 (1 second hold)
 *   Slot status shown as dots top-right of screen (yellow=saved, grey=empty)
 *
 * FUNC MODE (pads 7+8 to enter/exit):
 *   Bottom row pads 9-16 select a function (labels shown on screen):
 *     Pad 9  = KEY    — top row pads 1-8 select root note (C D Eb F G Ab Bb B)
 *     Pad 10 = RIFF   — pads 1-8 select preset riff pattern (DFLT/SQNCE/FUNK/MINI/JUMP/RAVE/SYNC/DARK)
 *     Pad 11 = SOUND  — top row pads 1-8 select synth voice
 *     Pad 12 = WALK   — top row pads 1-8 select note walk mode
 *                        p1=OFF  p2=4TH    p3=OCTWAVE p4=5TH
 *                        p5=BOUNCE  p6=MIN3RD  p7=VAMP3  p8=RANDOM
 *     Pad 13 = FX     — enters FX ASSIGN sub-mode
 *     Pad 14 = TEMPO  — top row pads 1-8 select preset BPM (100/110/120/128/133/138/145/160)
 *                        tap TEMPO pad repeatedly to set BPM by tap-tempo
 *     Pad 15 = PLEN   — top row pads 1-8 set length 1-8
 *                        bottom row pads 9-16 set length 9-16
 *     Pad 16 = PAT>   — top row pads 1-8 select pattern play mode:
 *                        p1=FWD  p2=CW (fwd then rev)  p3=ALT (odd/even)  p4=REV
 *                        p5=SKIP2 (every 2nd)  p6=SKIP3 (every 3rd)  p7=PING  p8=RND
 *
 * FX ASSIGN SUB-MODE (FUNC → pad 13):
 *   Phase 1: press top-row pads 1-8 to select an effect:
 *     Pad 1=None  Pad 2=Oct Up  Pad 3=Retrigger  Pad 4=Stutter
 *     Pad 5=Maj Step  Pad 6=Min Step  Pad 7=Dom7 Step  Pad 8=Dim Step
 *   Phase 2: press any pad 1-16 to assign that effect to that step
 *   Tap selected FX pad again to deselect
 *   Long-hold pad 1 = clear all step effects
 *   Pads 7+8 chord = exit FX assign to main screen
 *
 * EASTER EGG: ACID WALKS (pads 11+12+13+14, hold 1s):
 *   Toggles a hidden bank of 8 patterns inspired by classic acid/house
 *   tracks, each with its own preset key/tempo/length/sound.
 *   Pads 1-8 select a pattern. FUNC mode, FX assign, and drum mode all
 *   continue to work normally while active. Hold the same chord again
 *   to exit back to the normal pattern.
 *
 * ACCENT EDIT (pads 15+16, hold 1s):
 *   Toggles a mode where CUT/RES/DCY tune the accent envelope itself
 *   instead of the live filter:
 *     CUT = accent peak cutoff boost   RES = accent peak resonance boost
 *     DCY = accent decay-time (CCW=short/snappy, CW=long/dramatic)
 *   Normal CUT/RES/DCY values freeze while tuning. Hold the chord again
 *   to exit — settings save to EEPROM automatically and persist across
 *   power cycles until changed again.
 *
 * WIRING:
 *   TFT   : SCK=GP6, SDA=GP7, RST=GP8, DC=GP10, CS=GP13
 *   Pots  : CUT=GP26, RES=GP28, DCY=GP27
 *   Sync  : IN=GP2 (hold pad 14 at power-on to boot into Sync In mode)
 *   Audio : GP15 (100R + 10nF RC filter to output jack)
 *
 *   Pads (top row, steps 1-8 / FUNC apply):
 *     GP14=pad1  GP12=pad2  GP11=pad3  GP16=pad4
 *     GP17=pad5  GP19=pad6  GP20=pad7  GP21=pad8
 *
 *   Pads (bottom row, steps 9-16 / FUNC select):
 *     GP0=pad9   GP1=pad10  GP3=pad11  GP4=pad12
 *     GP5=pad13  GP9=pad14  GP18=pad15 GP22=pad16
 *
 * =====================================================================
 */

// =====================================================================
// MOZZI CONFIG - must precede all includes
// =====================================================================
#include "MozziConfigValues.h"
#define MOZZI_AUDIO_MODE     MOZZI_OUTPUT_PWM
#define MOZZI_ANALOG_READ    MOZZI_ANALOG_READ_NONE
#define MOZZI_AUDIO_PIN_1    15
#define MOZZI_AUDIO_RATE     16384
#define MOZZI_CONTROL_RATE   256

#include <Mozzi.h>
#include <SPI.h>
#include <Adafruit_GFX.h>
#include <Adafruit_ILI9341.h>
#include <EEPROM.h>

// ── Beat Machine 2 — forward declarations ────────────────────────────
extern bool   bmMode;
extern bool   bmFullDirty;
extern void   bmInit();
extern void   bmUpdateControl();
extern void   bmDoDraw();
extern void   bmStartAudio();
extern void   bmClearPadState();
extern bool   bmPotLocked;
extern uint8_t bmPotPickup;
extern void     bmTriggerStep(uint8_t step);
extern byte     bmStepDiv;
extern byte     bmPulseNum;
extern uint16_t bmStepNum;
extern byte     bmDrumPos;
extern bool   bmPlaying;
extern bool   bmPlayChanged;
extern void   bmFillDrumBuffer();
extern void   bmDrawDrumFlash();
extern uint32_t bmLastFlashDraw;
extern float    bmStoredTempo;
extern bool     bmPChord[16];
extern bool     bmPState[16];
extern void   bmSavePatch(uint8_t slot);
extern void   bmLoadPatch(uint8_t slot);
extern bool   bmSlotHasData[4];
extern void   bmCheckSlots();
extern void   bmResetToBasic();

bool     bmModeArmed = false;
uint32_t bmModeArmMs = 0;
#define BM_SW_A  8   // pad 9 (index 8) — mode switch pad A
#define BM_SW_B  9   // pad 10 (index 9) — mode switch pad B
bool     bmAcidWasRunning = false;  // legacy — no longer used for logic (kept to avoid extern breakage)
// acidPlaying: true when the acid sequencer should fire notes.
// Independent of bmPlaying and seq.running.
// seq.running = acidPlaying || bmPlaying (the shared clock ticks whenever
// either module is active; neither module stopping kills the other's clock).
bool     acidPlaying      = false;

// Easter egg: hold pads 11+12+13+14 (indices 10-13) together for ~1s to
// toggle "Acid Walks" — a value strip of 8 classic-acid-inspired patterns.
#define WALK_PAD_A 10  // pad 11
#define WALK_PAD_B 11  // pad 12
#define WALK_PAD_C 12  // pad 13
#define WALK_PAD_D 13  // pad 14
#define WALK_HOLD_MS 1000
bool     walksMode    = false;  // true while the Acid Walks value strip is shown
bool     walksArmed   = false;  // chord held, waiting for WALK_HOLD_MS
uint32_t walksArmMs   = 0;
uint8_t  curWalk      = 0;      // currently-loaded Acid Walks pattern index

// ACCENT EDIT: hold pads 15+16 (indices 14-15) together for ~1s to toggle
// a mode where the CUT/RES/DECAY pots tune the accent envelope itself
// (peak cutoff boost, peak resonance boost, and decay-time multiplier)
// instead of the live filter. Values are saved to EEPROM on exit so the
// "locked in" accent sound persists across power cycles.
#define ACCENT_PAD_A 14  // pad 15
#define ACCENT_PAD_B 15  // pad 16
#define ACCENT_HOLD_MS 1000
bool     accentEditMode  = false;  // true while CUT/RES/DECAY pots tune the accent envelope
bool     accentEditArmed = false;  // chord held, waiting for ACCENT_HOLD_MS
uint32_t accentEditArmMs = 0;
int16_t  accentEnvCutoff = 90;   // accent peak cutoff boost (0-255) — replaces hardcoded 90
int16_t  accentEnvRes    = 90;   // accent peak resonance boost (0-400) — replaces hardcoded 90
int16_t  accentDecayDiv  = 5;    // accent envelope decay divisor (1-10) — replaces hardcoded 5



// =====================================================================
// PINS
// =====================================================================
#define TFT_CS    13
#define TFT_RST    8
#define TFT_DC    10
#define TFT_MOSI   7
#define TFT_SCK    6
#define POT_CUT   26
#define POT_RES   28
#define POT_DECAY 27
#define SYNC_IN    2

// 16 pads — top row (steps 1-8): applies FUNC values / FX assign phase 1+2
//           bottom row (steps 9-16): selects FUNC function in FUNC mode
// Chord: pads 1+2 (indices 0+1) = PLAY/STOP, pads 7+8 (indices 6+7) = FUNC toggle
const uint8_t PAD_PINS[16] = {
  14,12,11,16,17,19,20,21,   // pads 1-8  (steps 1-8,  top row) — pad1=GP14, pad3=GP11 (swapped)
   0, 1, 3, 4, 5, 9,18,22    // pads 9-16 (steps 9-16, bottom row)
};

#define PAD_PLAY_A  0   // pads 1+2 pressed together = PLAY/STOP
#define PAD_PLAY_B  1
#define PAD_FUNC_A  6   // pads 7+8 pressed together = FUNC toggle
#define PAD_FUNC_B  7

// =====================================================================
// DISPLAY
// =====================================================================
#define SW 320
#define SH 240

// This forces MADCTL's MY (Y-mirror) bit on top of setRotation(3)'s own
// MADCTL value. Reason unconfirmed — possibly needed for a specific panel
// variant with reversed row addressing, but that has NOT been verified.
// What IS confirmed: on a standard ILI9341 panel this fights with
// setRotation(3) and produces the wrong orientation (see repo issue #2).
// Comment this out if your screen looks wrong after setRotation(3) with
// it enabled.
#define PANEL_NEEDS_Y_MIRROR

// Colour palette (RGB565)
#define C_BG    0x0000
#define C_WHT   0xFFFF
#define C_RED   0xF800
#define C_GRN   0x07E0
#define C_YEL   0xFFE0
#define C_CYN   0x07FF
#define C_ORG   0xFC60
#define C_DGR   0x4208
#define C_MGR   0x8410
#define C_BLU   0x001F
#define C_MGN   0xF81F  // magenta — accent indicator

// Step-grid colors (303-style warm amber, replacing plain greys for step cells)
#define C_AMB   0xFC60  // orange — active note bar fill, cursor cell background (matches title 'I')
#define C_AMBBG 0x3922  // dark amber-brown — active step cell background (non-cursor)
#define C_AMBBR 0x59C2  // amber-brown — empty step cell border
#define C_MGND  0x3009  // dark magenta — accent step cell background

Adafruit_ILI9341 tft = Adafruit_ILI9341(&SPI, TFT_DC, TFT_CS, TFT_RST);

// =====================================================================
// NOTE FREQUENCY TABLE
// =====================================================================
// Placed in RAM (see updateAudio comment) — avoids XIP contention with core 1's SPI traffic
const uint16_t __not_in_flash("audiotables") noteFreq[60] = {
  274,291,308,326,346,366,388,411,436,461,489,518,
  549,581,616,652,691,732,776,822,871,923,978,1036,
  1097,1163,1232,1305,1383,1465,1552,1644,1742,1845,1955,2071,
  2195,2325,2463,2610,2765,2930,3104,3288,3484,3691,3910,4143,
  4389,4650,4927,5220,5530,5859,6207,6577,6968,7382,7821,8286,
};

// =====================================================================
// WAVETABLES
// =====================================================================
const uint8_t __not_in_flash("audiotables") sinetable[256] = {
  127,130,133,136,139,142,145,148,151,154,157,160,163,166,169,172,
  175,178,181,184,186,189,192,194,197,200,202,205,207,209,212,214,
  216,218,221,223,225,227,229,230,232,234,235,237,239,240,241,243,
  244,245,246,247,248,249,250,250,251,252,252,253,253,253,253,253,
  254,253,253,253,253,253,252,252,251,250,250,249,248,247,246,245,
  244,243,241,240,239,237,235,234,232,230,229,227,225,223,221,218,
  216,214,212,209,207,205,202,200,197,194,192,189,186,184,181,178,
  175,172,169,166,163,160,157,154,151,148,145,142,139,136,133,130,
  127,123,120,117,114,111,108,105,102,99,96,93,90,87,84,81,
  78,75,72,69,67,64,61,59,56,53,51,48,46,44,41,39,
  37,35,32,30,28,26,24,23,21,19,18,16,14,13,12,10,
  9,8,7,6,5,4,3,3,2,1,1,0,0,0,0,0,
  0,0,0,0,0,0,1,1,2,3,3,4,5,6,7,8,
  9,10,12,13,14,16,18,19,21,23,24,26,28,30,32,35,
  37,39,41,44,46,48,51,53,56,59,61,64,67,69,72,75,
  78,81,84,87,90,93,96,99,102,105,108,111,114,117,120,123
};

const uint8_t __not_in_flash("audiotables") noisetable[64] = {
  232,175,188,102,142,3,70,116,17,139,22,155,54,118,84,22,
  251,228,160,233,30,32,6,125,16,216,122,189,95,232,135,205,
  181,97,90,80,76,170,0,4,123,183,46,163,185,40,47,208,
  145,67,219,87,74,140,213,10,72,51,29,142,230,63,204,123
};

const uint8_t __not_in_flash("audiotables") compressortable[256] = {
  0,1,3,5,7,9,10,12,14,16,18,19,21,23,25,27,
  28,30,32,34,36,37,39,41,43,45,46,48,50,52,54,55,
  57,59,61,63,64,66,68,70,72,73,75,77,79,81,82,84,
  86,88,90,91,93,95,97,99,100,102,104,106,108,109,111,113,
  115,117,118,120,122,124,126,127,129,131,133,135,136,138,140,142,
  144,145,147,149,151,153,154,156,158,160,162,163,165,167,169,171,
  172,174,176,178,180,181,183,185,187,189,190,192,194,196,198,199,
  201,203,205,207,208,210,212,214,216,217,219,221,223,225,226,228,
  228,228,228,228,228,229,229,229,229,229,230,230,230,230,230,231,
  231,231,231,231,232,232,232,232,233,233,233,233,233,234,234,234,
  234,234,235,235,235,235,235,236,236,236,236,237,237,237,237,237,
  238,238,238,238,238,239,239,239,239,239,240,240,240,240,241,241,
  241,241,241,242,242,242,242,242,243,243,243,243,243,244,244,244,
  244,245,245,245,245,245,246,246,246,246,246,247,247,247,247,247,
  248,248,248,248,249,249,249,249,249,250,250,250,250,250,251,251,
  251,251,251,252,252,252,252,252,253,253,253,253,254,254,254,255
};

// Per-sound pot mapping ranges [CUT_LO, CUT_HI, RES_LO, RES_HI]
// Resonance smoothing curve — applied to positive gResonance values only.
// Maps linear 0-508 through a power-1.6 curve so the resonance peak builds
// gradually from zero instead of jumping abruptly at the midpoint of the pot.
// Negative gResonance (damping side) is left linear and unchanged.
// Usage: if (gResonance > 0) gResonance = resCurve[gResonance];
const uint16_t __not_in_flash("audiotables") resCurve[512] = {
    0,  0,  0,  0,  0,  0,  0,  1,  1,  1,  1,  1,  1,  1,  2,  2,
    2,  2,  2,  3,  3,  3,  3,  4,  4,  4,  4,  5,  5,  5,  5,  6,
    6,  6,  7,  7,  7,  8,  8,  8,  9,  9,  9, 10, 10, 11, 11, 11,
   12, 12, 12, 13, 13, 14, 14, 14, 15, 15, 16, 16, 17, 17, 18, 18,
   18, 19, 19, 20, 20, 21, 21, 22, 22, 23, 23, 24, 24, 25, 25, 26,
   26, 27, 27, 28, 29, 29, 30, 30, 31, 31, 32, 32, 33, 34, 34, 35,
   35, 36, 37, 37, 38, 38, 39, 40, 40, 41, 41, 42, 43, 43, 44, 45,
   45, 46, 47, 47, 48, 48, 49, 50, 50, 51, 52, 53, 53, 54, 55, 55,
   56, 57, 57, 58, 59, 60, 60, 61, 62, 62, 63, 64, 65, 65, 66, 67,
   68, 68, 69, 70, 71, 71, 72, 73, 74, 74, 75, 76, 77, 78, 78, 79,
   80, 81, 82, 82, 83, 84, 85, 86, 86, 87, 88, 89, 90, 91, 91, 92,
   93, 94, 95, 96, 97, 97, 98, 99,100,101,102,103,104,104,105,106,
  107,108,109,110,111,112,112,113,114,115,116,117,118,119,120,121,
  122,123,124,125,125,126,127,128,129,130,131,132,133,134,135,136,
  137,138,139,140,141,142,143,144,145,146,147,148,149,150,151,152,
  153,154,155,156,157,158,159,160,161,162,163,164,165,167,168,169,
  170,171,172,173,174,175,176,177,178,179,180,182,183,184,185,186,
  187,188,189,190,191,193,194,195,196,197,198,199,200,201,203,204,
  205,206,207,208,209,211,212,213,214,215,216,218,219,220,221,222,
  223,225,226,227,228,229,230,232,233,234,235,236,238,239,240,241,
  243,244,245,246,247,249,250,251,252,254,255,256,257,258,260,261,
  262,263,265,266,267,268,270,271,272,274,275,276,277,279,280,281,
  282,284,285,286,288,289,290,291,293,294,295,297,298,299,301,302,
  303,305,306,307,309,310,311,313,314,315,317,318,319,321,322,323,
  325,326,327,329,330,331,333,334,336,337,338,340,341,342,344,345,
  347,348,349,351,352,354,355,356,358,359,361,362,363,365,366,368,
  369,370,372,373,375,376,378,379,380,382,383,385,386,388,389,391,
  392,393,395,396,398,399,401,402,404,405,407,408,410,411,412,414,
  415,417,418,420,421,423,424,426,427,429,430,432,433,435,436,438,
  439,441,442,444,446,447,449,450,452,453,455,456,458,459,461,462,
  464,465,467,469,470,472,473,475,476,478,480,481,483,484,486,487,
  489,491,492,494,495,497,498,500,502,503,505,506,508,508,508,508,
};

const int soundRange[11][4] = {
  {718,200,  70,1020},   // 0  SAW+LPF
  {670,260,  80,670},    // 1  SQR+LPF
  {670,0,    0,1020},    // 2  SINE+LPF
  {670,270,  80,1020},   // 3  NOISE+LPF
  {1020,250, 0,1020},    // 4  CSAW  — CUT reversed
  {1023,0,   0,1023},    // 5  CSQR  — CUT reversed
  {1020,600, 0,1020},    // 6  CSIN  — CUT reversed
  {1023,0,   1023,0},    // 7  NOISE+COMB
  {1023,0,   0,1023},    // 8  PWM
  {1023,0,   0,1023},    // 9  SUB SQUARE — RES=filter resonance(reversed), CUT=sub mix
  {0,1023,   0,1023},    // 10 WAVESHAPE
};

int restrictValue(int val, int mn, int mx) {
  long temp = mx - mn;
  temp *= (val < 0 ? 0 : (val > 1023 ? 1023 : val));
  temp /= 1023;
  return (int)(temp + mn);
}

// =====================================================================
// SYNTHESIS STATE
// =====================================================================
volatile uint16_t gFreq      = 287;
volatile uint16_t gTarget    = 287;
volatile int32_t  gFreqFP    = 287 << 8;  // 8.8 fixed-point; gFreq = gFreqFP >> 8
volatile int32_t  gGlideStep = 0;
volatile bool     gGlide     = false;
volatile bool     gPorta     = false;     // portamento — reserved for future use
volatile uint8_t  gPortaSpeed= 4;

volatile int16_t  gCutoff           = 64;
volatile int16_t  gCutoffDisplay    = 64;   // 0-255 for bar display (raw pot, no envelope)
volatile int16_t  gResonance        = 0;
volatile int16_t  gResonanceDisplay = 512;  // 0-1023 for bar display (512 = mid)
volatile int16_t  gVolSub    = 500;
volatile int16_t  gEnvCutoff = 0;    // envelope filter boost — peaks on note-on, decays with DCY
volatile int16_t  gEnvRes    = 0;    // accent resonance envelope boost — peaks on accented note-on, decays with DCY
volatile bool     gAccentActive = false;  // true while the current note's accent envelope is decaying
volatile uint8_t  gSound     = 0;
volatile uint8_t  gEffect    = 0;
volatile int16_t  gDecaySpeed= 2;
int16_t  lastDecaySpeed = 2;  // frozen gDecaySpeed value while accentEditMode is active
volatile uint32_t gLastStepMs= 0;

static uint16_t cnt = 0;
volatile int16_t filtA = 0;
volatile int16_t filtB = 0;
static uint8_t   combBuf[256];
static uint8_t   combPtr = 0;

volatile uint32_t lfoPos   = 0;
volatile int      lfoOffset= 0;
volatile uint8_t  phaseSw  = 128;

volatile uint16_t vFreq[8];
volatile uint16_t vCnt[8];
volatile uint16_t subFreq = 144;  // Sub Square oscillator frequency = gFreq/2 (sound 9)
volatile uint16_t subMix  = 0;    // Sub Square mix balance 0-1023 (sound 9)
static uint16_t subCnt = 0;       // Sub Square phase accumulator
volatile uint8_t  numV  = 1;
volatile uint8_t  volStd= 128;
volatile uint8_t  volClp= 128;

const int8_t __not_in_flash("audiotables") arpeggio[4][4] = {
  {0, 4, 7, 12},
  {0, 3, 7, 12},
  {0, 4, 7, 11},
  {0, 3, 6,  9},
};

// =====================================================================
// SEQUENCER
// =====================================================================
#define NUM_STEPS 16

struct Step {
  uint8_t note;
  bool    active;
  bool    accent;
  bool    glide;
  uint8_t effect;
};
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
void loop() {
  audioHook();
}

// =====================================================================
// CORE 1 — Display handler
// All SPI/TFT calls happen here, never in core 0.
// =====================================================================
void setup1() {
  rp2040.fifo.pop();  // wait for core 0 setup to complete
}

void loop1() {
  // Fill drum buffer first — always top priority, must not starve
  bmFillDrumBuffer();

  // Handle mode switch signal from core 0. Drain the FIFO so any queued
  // duplicate/stale messages don't cause repeated fillScreen() calls that
  // leave the display blank for multiple loop1() passes — keep only the
  // most recent message.
  uint32_t fifoMsg;
  bool gotSwitch = false;
  uint32_t lastMsg = 0;
  while (rp2040.fifo.pop_nb(&fifoMsg)) {
    if (fifoMsg == 2 || fifoMsg == 3) { gotSwitch = true; lastMsg = fifoMsg; }
  }
  if (gotSwitch) {
    tft.fillScreen(0x0000);
    bmFillDrumBuffer();  // refill after screen clear (slow)
    if (lastMsg == 2) {
      bmFullDirty = true;
      bmDoDraw();
    } else {
      ui.fullDirty = false;  // consume the flag; drawMain() below does the work
      drawMain();
    }
    bmFillDrumBuffer();  // refill after draw
    return;
  }

  if (bmMode) {
    bmDoDraw();
    bmFillDrumBuffer();
  }
  if (saveCommit) {
    saveCommit = false;
    EEPROM.commit();
  }
  if (bmMode) return;

  // Save progress bar — only redraws when pct changes (drawSaveProgress is self-throttled)
  if (ui.slotProgressShow) {
    drawSaveProgress(ui.slotProgress);
  }
  // Save/load confirmation banner
  else if (ui.slotOverlay) {
    drawSlotOverlay();
  }
  else if (ui.fullDirty || ui.editDirty || ui.funcDirty ||
      ui.cellsDirty || ui.barDirty || ui.valDirty || ui.infoDirty) {
    ui.dirty = false;
    doDraw();
  } else {
    // Cursor tracking during playback
    uint32_t now1 = millis();
    if (seq.running && !fxAssignMode) {
      uint32_t msSinceStep = now1 - gLastStepMs;
      if (msSinceStep > 40 && msSinceStep < 80 && (now1 - ui.lastMs) > 60) {
        ui.lastMs = now1;
        static uint8_t prevCurDisp = 255;
        if (prevCurDisp != seq.cur) {
          if (prevCurDisp != 255) drawStepCell(prevCurDisp);
          drawStepCell(seq.cur);
          prevCurDisp = seq.cur;
        }
      }
    }
  }
  delay(4);
}

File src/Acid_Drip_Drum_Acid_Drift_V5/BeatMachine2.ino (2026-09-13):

/*
 * =====================================================================
 *  BEAT MACHINE 2  —  Acid Drip RP2040, standalone sketch
 *  Audio engine: DrumKid (Matt Bradshaw), ported by Marcus / lonesoulsurfer
 * =====================================================================
 *
 * SCREEN LAYOUT (320×240 landscape):
 *   y=0-11    Slot dots  (4 circles above pads 3-6)
 *   y=12-21   Step grid  (5 drum rows × 2px)
 *   y=24-43   Value strip
 *   y=46-83   Pad row 0  (beats 1-8, square pads)
 *   y=85-122  Pad row 1  (beats 9-16, square pads)
 *   y=125-140 FUNC label strip
 *   y=143-166 Pot bars
 *   y=170-239 Info strip
 *
 * DRUM EDIT (normal mode):
 *   Hold pad 1-5 (kick/hat/snare/rim/tom) while turning pots:
 *     CUT = pitch   RES = crop/length   DCY = volume
 *   Pot pickup prevents jumps on entry.
 *   Resets to defaults on pattern change.
 *   Saved/loaded with slots.
 *
 * FUNC MODE (pads 7+8):
 *   PTCH=global pitch  DRIV=drive/saturation  FILT=bipolar DJ filter
 *   CHNC=per-hit drop chance  HMNZ=velocity humanize  SWNG=16th swing
 *   ACNT=accent depth  FILL=procedural fill engine
 *
 * SAVE/LOAD: hold pads 7+8, then tap/hold pads 3-6
 * RESET:     hold pads 1+2 for 1 second
 * =====================================================================
 */


// =====================================================================
// BEAT MACHINE 2 — Tab for Acid Drip V4
// Place this file in the same folder as Acid_Drip_V4.ino
// =====================================================================

bool bmMode = false;

// ── Acid synth — forward declarations ────────────────────────────────
// ── Acid synth — forward declarations ────────────────────────────────
// BM drum saves/loads are fully independent (BM EEPROM offset 256+).
// Only these cross-module variables are needed from drum mode:
extern volatile bool saveCommit;
// Combined save/load — defined in Acid_Drip_V5.ino. The save/load gesture
// here in drum mode calls these instead of bmSavePatch()/bmLoadPatch()
// directly, so a save from the drum screen also captures acid + DRIFT
// (and vice versa) into the same slot. See the COMBINED SAVE / LOAD
// comment in Acid_Drip_V5.ino for the reasoning.
extern void saveAllToSlot(uint8_t slot);
extern void loadAllFromSlot(uint8_t slot);
extern bool comboSlotHasData(uint8_t slot);
// MIX EDIT trim/boost — Q8 gain (256=unity, up to ~384=1.5x boost), set via
// the CUT/RES/DECAY pots in Acid_Drip_V5.ino's mixEditMode and recomputed
// there by recomputeMixGains(). Applied here to DRIFT and the drum bus
// right where they're mixed together (see bmFillDrumBufferTo).
extern bool     mixEditMode;   // MIX EDIT borrows CUT/RES/DECAY — suspend drum pot edits
extern uint16_t mixDriftGainQ8;
extern uint16_t mixDrumGainQ8;
// DRIFT (second synth voice) lives on THIS output — GP2 — additively
// summed with drums below (bmFillDrumBufferTo()), blended against acid on
// GP15 at the PCB's shared audio node by the physical mix pot. It briefly
// rendered on GP15 instead, mixed digitally with acid in software; moved
// back so the physical pot has a real, separate DRIFT signal to blend —
// see the DRIFT OUTPUT comment near ch2SynthMode's declaration in the
// main sketch for the full reasoning.
extern uint8_t  ch2Wave;
extern uint8_t  ch2Sound;                     // 0-15, selected engine — see CH2_SND_NAMES
extern uint8_t  ch2Amount;                    // 0-255, live per-engine character knob (DCY pot)
extern volatile uint32_t ch2Phase;
extern volatile uint32_t ch2PhaseInc;
extern volatile uint16_t ch2Env;
extern volatile uint16_t ch2EnvM;
extern volatile uint32_t ch2DetuneRatioQ16;   // Q16 second-voice ratio — DTSQR + UNISN
extern volatile uint8_t  ch2ClickCount;       // CLICK: noise-burst samples remaining
extern volatile uint8_t  ch2NoiseIdx;         // CLICK: running index into noisetable[]
extern int16_t  ch2EchoBuf[];                 // ECHO delay line (CH2_ECHO_LEN samples, power of 2)
extern volatile uint16_t ch2EchoDelay;        // ECHO delay in samples, 0 = off
extern volatile uint8_t  ch2EchoFb;           // ECHO feedback, Q8
extern Ch2VerbBufs ch2VerbBufs;               // VERB comb/allpass delay lines (~4.9KB)
extern volatile uint8_t  ch2VerbFbQ8;         // VERB comb feedback (room size), Q8
extern volatile uint8_t  ch2VerbWetQ8;        // VERB wet mix, Q8; 0 = off
extern const uint8_t sinetable[256];
extern const uint8_t noisetable[64];
// Note: acidPlaying is no longer referenced from this file. Drum and acid
// play state are fully independent — starting/stopping one never touches
// the other. See the PLAY/STOP chord handler below and its mirror in
// Acid_Drip_V4.ino.
bool bmAlarmStarted = false;
bool bmPlayChanged = false;  // signals V4 to sync acid play state
byte bmDrumPos  = 0;   // persistent drum pattern position (0-31)
// ── Fill engine ──────────────────────────────────────────────────────
// Procedural fills take over the last 4-8 steps before a boundary (length
// scales with frequency). Density accelerates into a kick+openhat landing.
byte     bmFillMode = 0;   // 0=off  1=every 1 bar  2=every 2 bars  3=every 4 bars
byte     bmFillType = 0;   // 0=HATS  1=CLAP  2=SNARE  3=KIT (tom descent -> snare)
uint16_t bmAbsStep  = 0;   // free-running step counter (fill phase), resets on play
bool     bmWasInFill = false;   // was the previous step inside a fill? (for landing)
// Each fill type's LEAD voice (HATS=hihat CLAP=clap SNARE=snare KIT=tom) has its
// own locked sound (bmFillPitch/Len/Vol — declared with the drum arrays below,
// since they need NUM_DRUMS). Applied during the fill, restored after.
uint8_t  bmFillTouched = 0;     // bitmask of voices given fill sound (need restore)
// Density acceleration: schedule one 32nd-note in-between hit, fired from
// bmUpdateControl. Same mechanism as the old double-time, but fill-only.
bool     bmFillDblPending = false;
uint32_t bmFillDblDueUs   = 0;
byte     bmFillDblDrum     = 0;
uint8_t  bmFillDblGain     = 0;   // final gain for the scheduled 32nd (vol already folded in)
uint32_t bmHumanizeJitUs = 0;     // max late jitter (us) at the current HMNZ setting
// Pot pickup for in-fill drum editing: on a target-drum switch all three
// pots lock, each releasing only once physically moved (movement-gated),
// so a returned-to drum keeps its own values until you touch a pot.
int8_t   bmFillEditDrum = -1;
bool     bmFillPotLock[3] = {true,true,true};   // 0=CUT/pitch 1=RES/len 2=DCY/vol
uint8_t  bmFillPotRef[3]  = {0,0,0};            // pot position captured at lock
#define NUM_DRUMS 8
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
